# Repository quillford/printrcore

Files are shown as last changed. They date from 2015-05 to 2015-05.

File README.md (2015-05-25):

# smartcore
the simple and cheap corexy from smartfriendz

Note: this is still a work in progress

# Printrbot Simple
this branch concerns converting your Printrbot Simple into a smartcore

Most of the vitamins (non printable parts) can be reused from the printrbot (e.g. printrboard, rods).

# OpenJSCAD Parameters
These are the parameters you should enter in OpenJSCAD

For the stock printrbot simple 1405:

* Output Resolution: 32
* Print width: 110
* Print height: 100
* Print depth: 100
* Box Wood thickness: whatever you are using
* X Y Rods diameter: ~8.1 (can be increased if needed)
* Z Rods diameter: ~8.1 (can be increased if needed)
* Z threaded rods: true
* Stepper motors type: nema17

# Reused Vitamins
* Smooth Rods
* Power supply
* Printrboard
* endstops
* Z probe
* bed
* Hotend
* Extruder (Possibly)
* Motors
* LM8UU Bearings
* Fan

# New Vitamins
* Bowden push fit connectors
* Bowden tube
* GT2 Belt (longer than stock printrbot)
* 608zz bearings
* Wood (for frame)
* Heated bed (optional but recommended)

# Extra Printed Parts
Needed:

* [JHead to Ubis adapter](https://github.com/lordofhyphens/jheadtoubis/blob/master/ubis_jhead_adapter_bracket.stl)

Optional:

* [Printrboard cover](http://www.thingiverse.com/thing:278789/#files)

# Build Notes
* The X axis endstop wires will need to be extended.

# Heated Bed
This is an optional but recommended upgrade for the Printrbot/Smartcore.

Sources:
* [Amazon - Silicon Heater](http://www.amazon.com/100x100mm-Silicone-Rubber-Heater-Printer/dp/B00I50G4O8)
* [Official Printrbot heated bed](http://printrbot.com/shop/heated-bed-upgrade-for-makers-kit-1405/)
* [Ebay - PCB Heater](http://www.ebay.com/itm/Prewired-Heatbed-For-Printrbot-Simple-4-65-X-7-25-Heated-Bed-for-3D-Printing-/251620873437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)

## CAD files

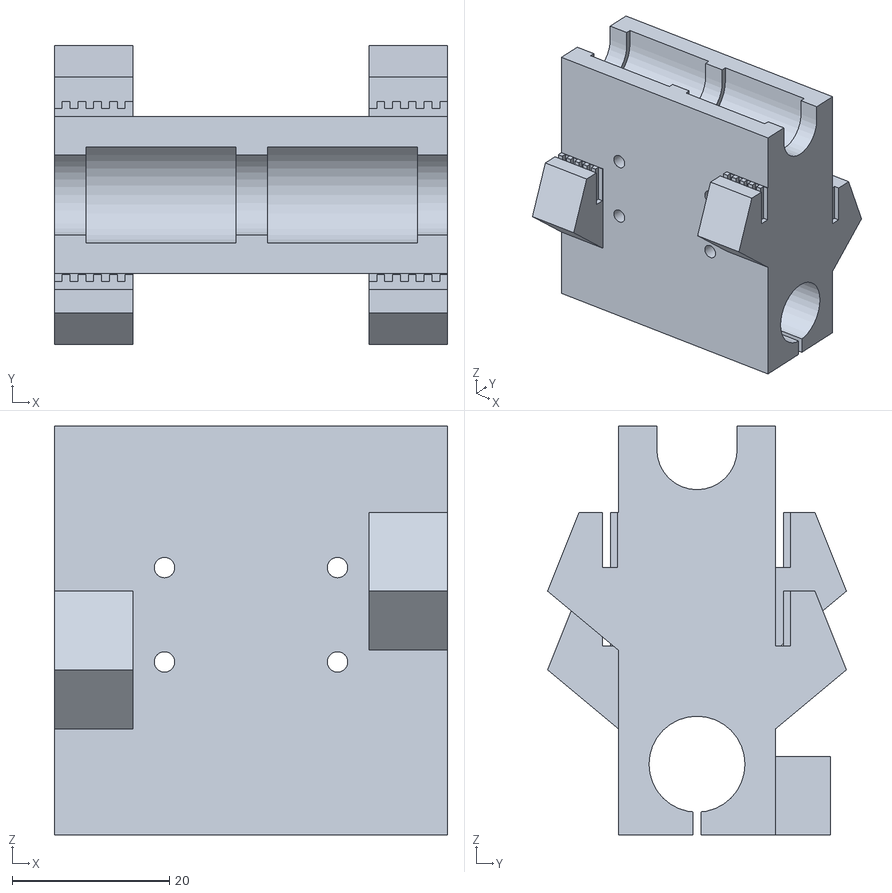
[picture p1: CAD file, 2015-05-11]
stl/separate parts/basic version/head.stl
50.0 x 38.0 x 52.0

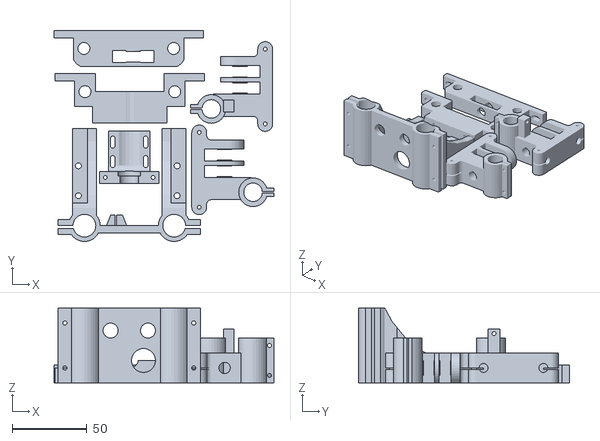
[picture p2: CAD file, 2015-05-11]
stl/smartrapcore_plate1.stl
147.1 x 141.1 x 50.0

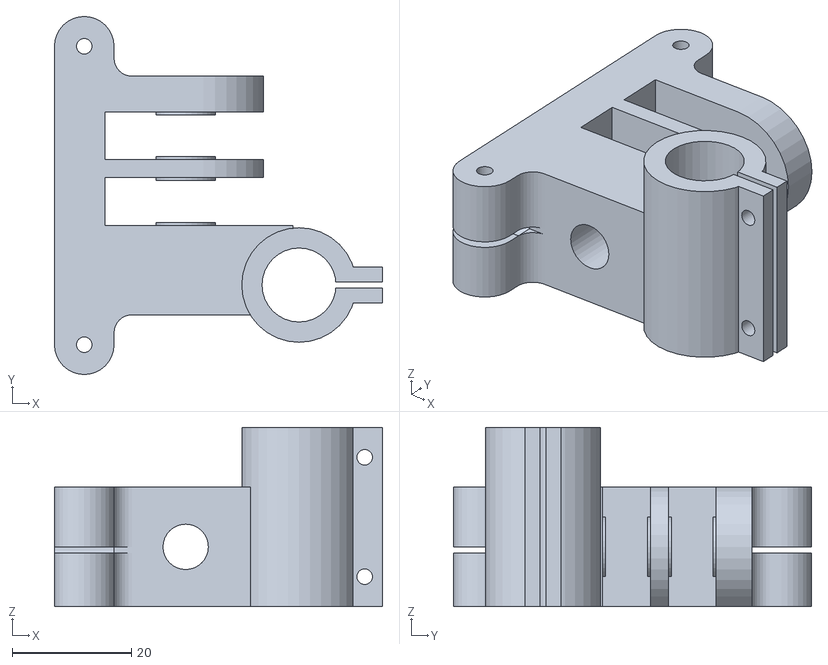
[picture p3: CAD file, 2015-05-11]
stl/separate parts/basic version/Yslide_right.stl
55.0 x 60.0 x 30.0

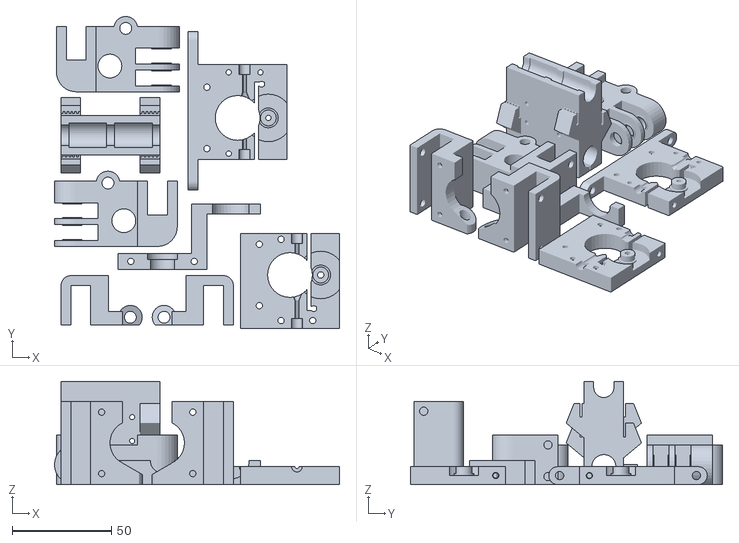
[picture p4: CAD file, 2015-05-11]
stl/smartrapcore_plate2.stl
143.9 x 157.4 x 52.0

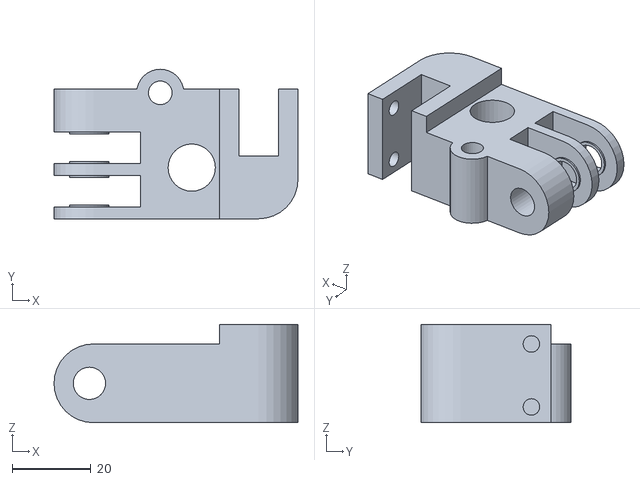
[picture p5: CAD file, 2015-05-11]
stl/separate parts/basic version/XYbearings_left.stl
62.0 x 38.0 x 25.0

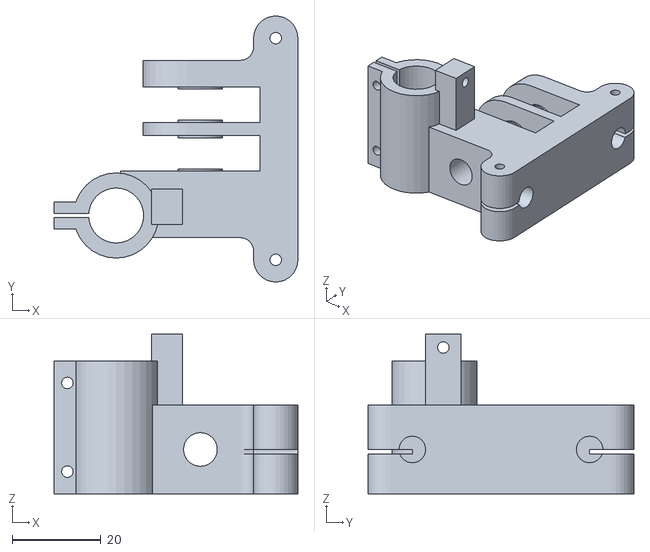
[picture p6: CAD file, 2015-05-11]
stl/separate parts/basic version/Yslide_left.stl
55.0 x 60.0 x 36.0

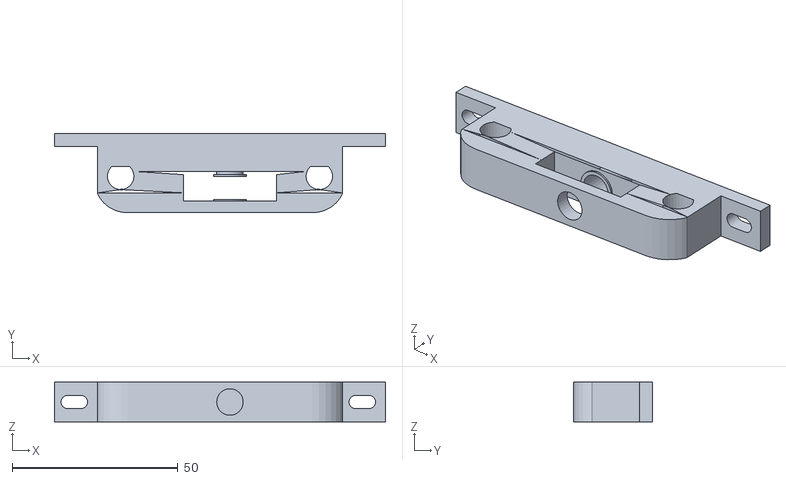
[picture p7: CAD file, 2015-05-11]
stl/separate parts/basic version/Ztop.stl
100.0 x 24.0 x 12.0

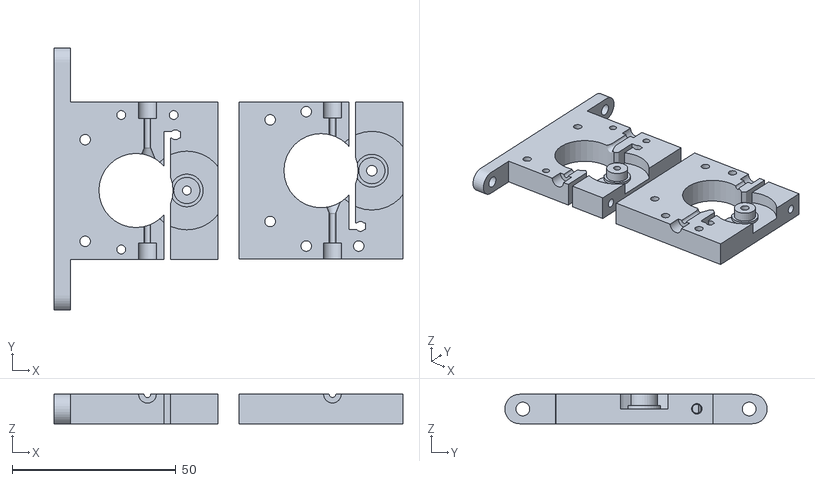
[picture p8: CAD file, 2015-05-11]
stl/separate parts/basic version/extruder_mk8_doublepressfit.stl
106.4 x 80.0 x 9.00

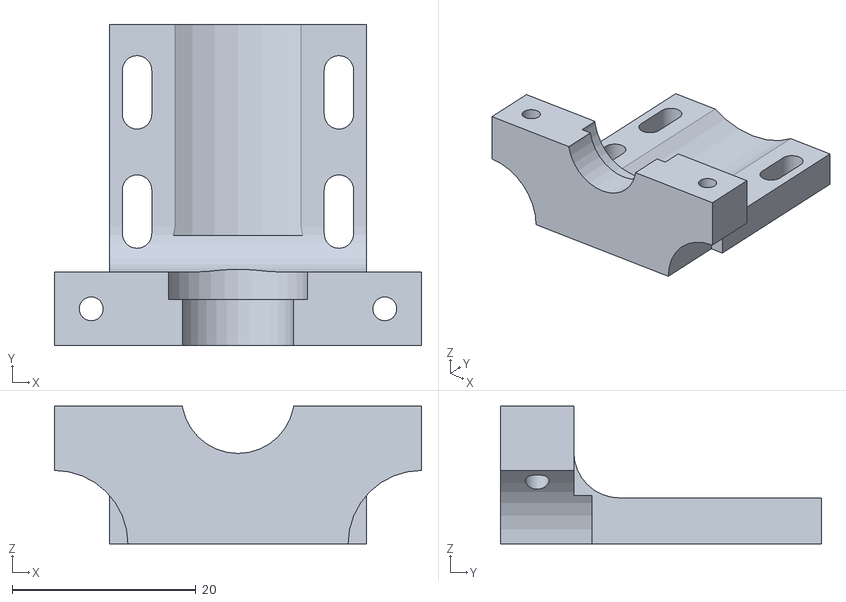
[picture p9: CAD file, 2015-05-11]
stl/separate parts/basic version/jhead_attach.stl
40.0 x 35.0 x 15.0

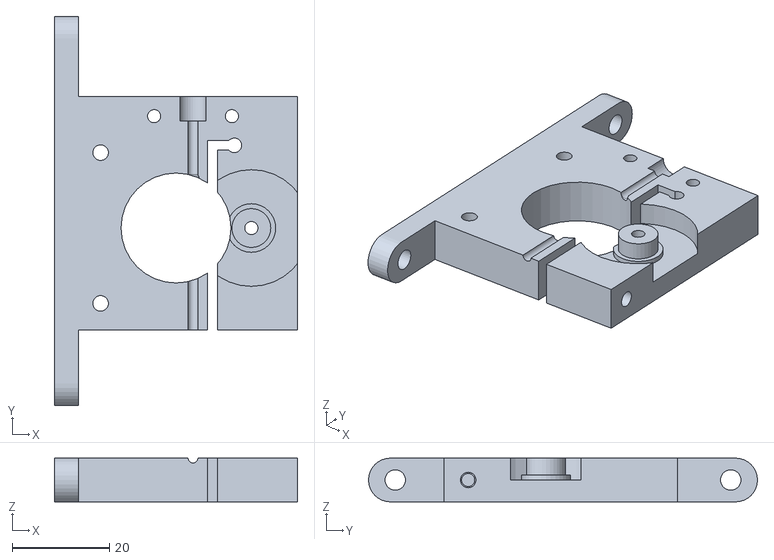
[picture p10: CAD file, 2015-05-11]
stl/separate parts/basic version/extruder_bowden_bottom_mk8.stl
50.0 x 80.0 x 9.00

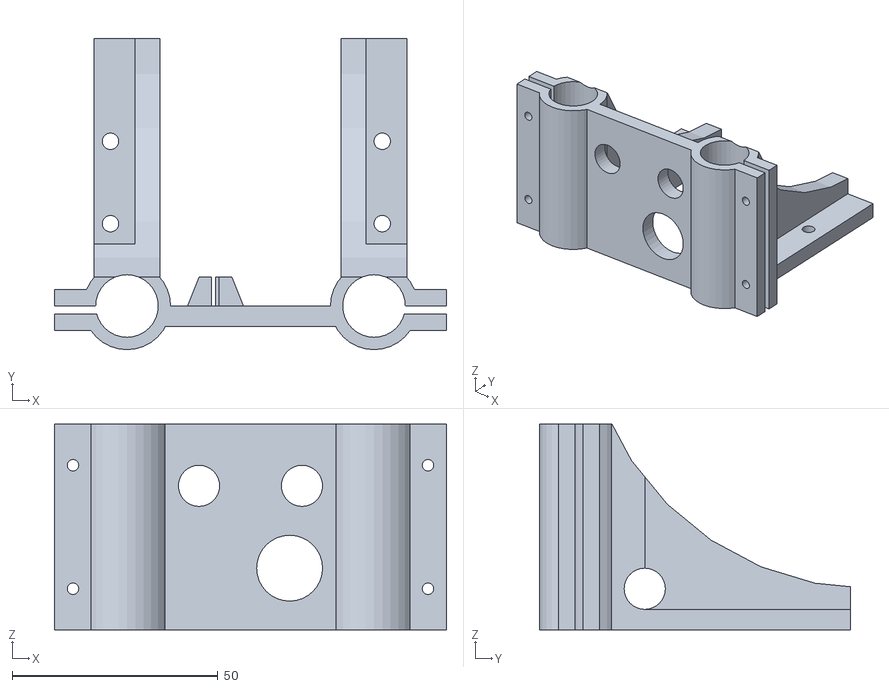
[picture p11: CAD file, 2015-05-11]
stl/separate parts/basic version/Zslide.stl
95.2 x 75.6 x 50.0

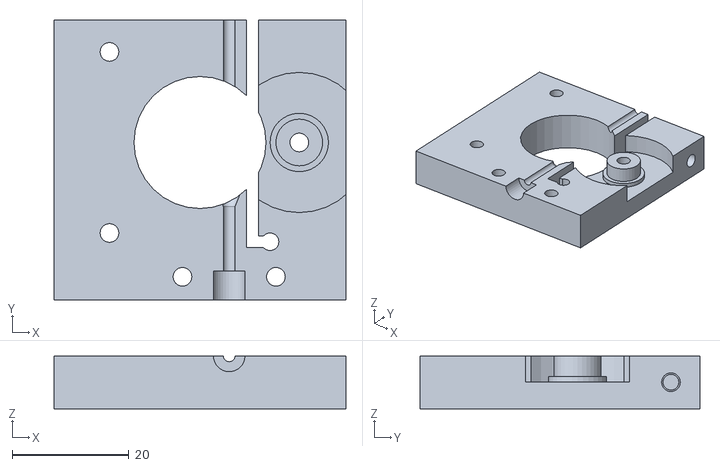
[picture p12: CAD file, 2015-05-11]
stl/separate parts/basic version/extruder_bowden_top_mk7.stl
50.0 x 48.0 x 9.00

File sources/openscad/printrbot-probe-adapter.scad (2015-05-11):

outer_dim=18.2;
probe_dim=12;
rim_dim=outer_dim+3;

length=8.31 + 56.28;

difference() {
  union() {
    cylinder(r=rim_dim/2, h=2);
    cylinder(r=outer_dim/2, h=length);
  }
  cylinder(r=probe_dim/2, h=length, $fs=0.1);
}

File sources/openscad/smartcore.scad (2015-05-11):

/**********

Smartcore : L'empileuse

author= serge.vi / smartfriendz
licence : GPL
version: 0.1
date: 11 / 2014



TODO:





***********/

// global s - updated from interface but need to be avalaible in all modules
_globalResolution=8;
_woodsupport=false;
_globalWidth=300; // exernal dimension of the all printer
_globalHeight=300; // exernal dimension of the all printer
_globalDepth=300; // exernal dimension of the all printer
_printableWidth=200;
_printableDepth=200;
_printableHeight=150;
_wallThickness=10; // box wood thickness
_XYrodsDiam=6; // usually 6 or 8 .. or 10? 
_XYlmDiam=12; // lm6uu, lm8uu ... will be calculated from rods diam
_ZrodsDiam=8; // usually 6 or 8 .. or 10? 
_ZlmDiam=15; // lm6uu, lm8uu ... will be calculated from rods diam
_nemaXYZ=42;  // nema 14 , nema 17 
_XrodsWidth=40; //space between rods on X axis
_ZrodsWidth=80; //space between rods on Z axis
_extrusionType = 0; // 0 bowden 1 direct
 XrodLength = 300; // will be calculated in main from parameters.
 YrodLength = 300; // will be calculated in main from parameters.
 ZrodLength = 300; // will be calculated in main from parameters.
 _rodsSupportThickness = 3; // thickness around rods for all supports
 outputPlateWidth = 180; //used when output to printable plates for elements
 outputPlateDepth = 180;
 mk7Diam = 10;

// global for work
 _bearingsDepth = 35; 
 XaxisOffset = -80;
 _ZaxisOffset = -30;
 endxJheadAttachHolesWidth = 32;




/*
    _globalDepth = _printableDepth + 120; // = motor support depth + bearings depth + head depth /2
    _globalWidth = _printableWidth + 120; // = motor uspport width + bearings width + head width /2
    _globalHeight = _printableHeight + 100; // bottom = 40mm head = 40 mm + extra loose.

    XrodLength = _globalWidth - 2*(40 + 3); // 40: slideY width , 3: offset slideY from wall.
    YrodLength = _globalDepth - (_nemaXYZ -5) - (_bearingsDepth -5); // 5: rod support inside parts.
    ZrodLength = _globalHeight -40;


    echo("wood depth="+_globalDepth + " width="+_globalWidth+" height:"+_globalHeight);
    echo("X rod length="+XrodLength + " Y rod length="+YrodLength+" Zrodlength="+ZrodLength);
    // calculate some usefull s
     ztopbottomX = (_ZrodsWidth+_ZrodsDiam+(_rodsSupportThickness*2))/2;
     zslideX = (_ZrodsWidth+_ZlmDiam+(_rodsSupportThickness*2))/2;
*/
// -----------------  printed elements 

assembly();
zBottom();

module zTop(){
     width = _ZrodsWidth+_ZrodsDiam+(_rodsSupportThickness*2);
     height = 12;
     depth = 22;
     insideWidth = 60;

    if(output==1){
        union(){
            rotate([90,0,0])
            translate([3,0,0])
            bearing608z();
        };
    }
    union(){
        difference(){
            //main
            cube([width,depth,height],center=true);
            // inside form
            translate([0,-5,0])
            cube([insideWidth,depth,height],center=true);
            //screw left
            rotate([90,90,0])
            translate([-(insideWidth)/2+4,20,0])
            slottedHole(4,8,depth);
            //screw right
		rotate([90,90,0])
		translate([(insideWidth)/2-9,20,0])
            slottedHole(4,8,depth);
            // z rod left
		translate([-_ZrodsWidth/2,-2,-height/2])
            cylinder(r= _ZrodsDiam/2,h=height,fn=_globalResolution);
            //z rod right
		translate([_ZrodsWidth/2,-2,-height/2])
            cylinder(r=_ZrodsDiam/2,h=height,fn=_globalResolution);
            // chamfer
		rotate([90,0,0])
		translate([-(insideWidth)/2-5,-7,-height/2])
            roundBoolean(10,10,20,height,"bl");
		rotate([90,0,-90])
		translate([(insideWidth)/2+5,-7,-height/2])
            roundBoolean(10,10,20,height,"bl");

        };
		rotate([90,0,0])
		translate([3,6,0])
        bearingSupport(7);
    };
}

module zBottom(){
     width = _ZrodsWidth+_ZrodsDiam+(_rodsSupportThickness*2);
     height = 10;
     depth = 22;
     attachdiam = 12;
    difference(){
        //main
        union(){
            cube([width,depth,height],center=true);
            translate([0,-10,0])
            cube([width/2,depth,10],center=true);
            // screws attach form right
		rotate([-90,0,0])
		translate([width/4+attachdiam/2,depth/2-5,height])
            cylinder(r=attachdiam/2,h=5,fn=_globalResolution);
		translate([width/4+attachdiam/2,depth/2-2.5,height-attachdiam/2])
            cube([attachdiam,5,attachdiam],center=true);
            // screws attach form left
		rotate([-90,0,0])
		translate([-width/4-attachdiam/2,depth/2-5,height])
            cylinder(r=attachdiam/2,h=5,fn=_globalResolution);
		translate([-width/4-attachdiam/2,depth/2-2.5,height-attachdiam/2])
            cube([attachdiam,5,attachdiam],center=true);
            
	};
        // inside form
	rotate([90,0,0])
	translate([0,0,_nemaXYZ/2-height/2])
        nemaHole(_nemaXYZ);
	translate([0,10,0])
        cube([width/2,depth,height],center=true);
        // z rod left
	translate([-_ZrodsWidth/2,-2,-height/2])
        cylinder(r=_ZrodsDiam/2,h=height,fn=_globalResolution);
        //z rod right
	translate([_ZrodsWidth/2,-2,-height/2])
        cylinder(r=_ZrodsDiam/2,h=height,fn=_globalResolution);
        //screw holes
        // screws attach form
	rotate([-90,0,0])
	translate([width/4+attachdiam/2,depth/2-5,height])
        cylinder(r=2,h=5,fn=_globalResolution);
	rotate([-90,0,0])
	translate([-width/4-attachdiam/2,depth/2-5,height])
        cylinder(r=2,h=5,fn=_globalResolution);
        
};
}

module slideZ(){
     width = _ZrodsWidth-5;
     height = 50;
     depth = 5;
     insideWidth = 35;
    difference(){
        //main form
        union(){
            cube([width,depth,height]);
		rotate([90,0,0])
        translate([width/2-10,1,height-13])
            Gt2Holder2();
        
            // lm8uu holes
            translate([0,0,0])
            cylinder(r=_ZlmDiam/2+3,h=height,fn=_globalResolution);
            translate([_ZrodsWidth,0,0])
            cylinder(r=_ZlmDiam/2+3,h=height,fn=_globalResolution);

            // side forms for lm8 attach
            translate([_ZrodsWidth+7,-4,0])
            cube([10,10,height]);
            translate([-17,-4,0])
            cube([10,10,height]);

            // extra forms front bearings holes
            translate([-5,-75,0])
            cube([10,80,height]);
            translate([_ZrodsWidth-5,-75,0])
            cube([10,80,height]);
            
        };
        // big hole middle
        rotate([90,0,0])
        translate([width/2+15,40,height/2+10])
        cylinder(r=10,h=50,fn=_globalResolution);
        rotate([90,0,0])
        translate([width/2-10,40,height/2-10])
        cylinder(r=10,h=50,fn=_globalResolution);
        //  boolean front horizontal
        rotate([0,90,0])
        translate([-20,-80,-35])
        cylinder(r=80,h=width+40,fn=_globalResolution);
        rotate([0,90,0])
        translate([-20,-15,height-10])
        cylinder(r=5,h=width+40,fn=_globalResolution);
        rotate([0,90,0])
        translate([-20,-35,height-13])
        cylinder(r=3,h=width+40,fn=_globalResolution);
        // z rod left linear bearing lm
        cylinder(r=_ZlmDiam/2,h=height,fn=_globalResolution);
        //z rod right linear bearing lm
        translate([_ZrodsWidth,0,0])
        cylinder(r=_ZlmDiam/2,h=height,fn=_globalResolution);
        // side holes for lm8 attach
        translate([_ZrodsWidth+5,0,0])
        cube([12,2,height]);
        translate([-18,0,0])
        cube([12,2,height]);
        // side holes for lm8 screws
        rotate([90,0,0])
        translate([_ZrodsWidth+12,20,height-10])
        cylinder(r=1.4,h=30,fn=_globalResolution);
        rotate([90,0,0])
        translate([_ZrodsWidth+12,20,10])
        cylinder(r=1.4,h=30,fn=_globalResolution);
        rotate([90,0,0])
        translate([-12,20,height-10])
        cylinder(r=1.4,h=30,fn=_globalResolution);
        rotate([90,0,0])
        translate([-12,20,10])
        cylinder(r=1.4,h=30,fn=_globalResolution);
        //bottom holes

        //cylinder(r=2.4,h=10,fn=_globalResolution).rotateX(83).rotateZ(5).translate([0,-7,10]);
        //cylinder(r=2.4,h=10,fn=_globalResolution).rotateX(83).rotateZ(-5).translate([_ZrodsWidth,-7,10]);
        // top holes
        translate([0,-20,height-30])
        cylinder(r=1.4,h=30,fn=_globalResolution);
        translate([_ZrodsWidth,-20,height-30])
        cylinder(r=1.4,h=30,fn=_globalResolution);
        translate([0,-65,height-30])
        cylinder(r=1.4,h=30,fn=_globalResolution);
        translate([_ZrodsWidth,-65,height-30])
        cylinder(r=1.4,h=30,fn=_globalResolution);
        // special hole in gt2 holder to be able to get the belt out .. but still printable vertically.
        rotate([0,-90,0])
        translate([width/2+5,-10,height-15])
        linear_extrude(height=20,polygon([[0,0],[6,0],[4,10],[2,10]]));

        
    };
}
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

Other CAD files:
stl/separate parts/basic version/jhead_adaptor.stl
stl/separate parts/basic version/XYbearings_right.stl
stl/separate parts/basic version/extruder_bowden_top_mk8.stl
stl/separate parts/basic version/extruder_bowden_bottom_mk7.stl
sources/blender/sc_12_plates.blend

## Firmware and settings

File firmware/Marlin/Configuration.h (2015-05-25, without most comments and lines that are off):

#define CONFIGURATION_H
#include "boards.h"
#define STRING_VERSION_CONFIG_H __DATE__ " " __TIME__ // build date and time
#define STRING_CONFIG_H_AUTHOR "(none, default config)" // Who made the changes.
#define SERIAL_PORT 0
#define BAUDRATE 250000
  #define MOTHERBOARD BOARD_PRINTRBOARD
#define SDSUPPORT
#define EXTRUDERS 1
#define POWER_SUPPLY 1
#define TEMP_SENSOR_0 1
#define TEMP_SENSOR_1 0
#define TEMP_SENSOR_2 0
#define TEMP_SENSOR_BED 1
#define MAX_REDUNDANT_TEMP_SENSOR_DIFF 10
#define TEMP_RESIDENCY_TIME 10  // (seconds)
#define TEMP_HYSTERESIS 3       // (degC) range of +/- temperatures considered "close" to the target one
#define TEMP_WINDOW     1       // (degC) Window around target to start the residency timer x degC early.
#define HEATER_0_MINTEMP 5
#define HEATER_1_MINTEMP 5
#define HEATER_2_MINTEMP 5
#define BED_MINTEMP 5
#define HEATER_0_MAXTEMP 275
#define HEATER_1_MAXTEMP 275
#define HEATER_2_MAXTEMP 275
#define BED_MAXTEMP 150
#define PIDTEMP
#define BANG_MAX 255 // limits current to nozzle while in bang-bang mode; 255=full current
#define PID_MAX BANG_MAX // limits current to nozzle while PID is active (see PID_FUNCTIONAL_RANGE below); 255=full current
  #define PID_FUNCTIONAL_RANGE 10 // If the temperature difference between the target temperature and the actual temperature
  #define PID_INTEGRAL_DRIVE_MAX PID_MAX  //limit for the integral term
  #define K1 0.95 //smoothing factor within the PID
  #define PID_dT ((OVERSAMPLENR * 10.0)/(F_CPU / 64.0 / 256.0)) //sampling period of the temperature routine
 #define DEFAULT_Kp  52.65
 #define DEFAULT_Ki 6.43
 #define DEFAULT_Kd 107.83
#define PIDTEMPBED
#define MAX_BED_POWER 255 // limits duty cycle to bed; 255=full current
     #define  DEFAULT_bedKp 219.58
 #define  DEFAULT_bedKi 32.29
 #define  DEFAULT_bedKd 373.26
#define PREVENT_DANGEROUS_EXTRUDE
#define PREVENT_LENGTHY_EXTRUDE
#define EXTRUDE_MINTEMP 170
#define EXTRUDE_MAXLENGTH (X_MAX_LENGTH+Y_MAX_LENGTH) //prevent extrusion of very large distances.
#define COREXY
#define ENDSTOPPULLUPS // Comment this out (using // at the start of the line) to disable the endstop pullup resistors
  #define ENDSTOPPULLUP_XMAX
  #define ENDSTOPPULLUP_YMAX
  #define ENDSTOPPULLUP_ZMAX
  #define ENDSTOPPULLUP_XMIN
  #define ENDSTOPPULLUP_YMIN
  #define ENDSTOPPULLUP_ZMIN
const bool X_MIN_ENDSTOP_INVERTING = false; // set to true to invert the logic of the endstop.
const bool Y_MIN_ENDSTOP_INVERTING = false; // set to true to invert the logic of the endstop.
const bool Z_MIN_ENDSTOP_INVERTING = true; // set to true to invert the logic of the endstop.
const bool X_MAX_ENDSTOP_INVERTING = true; // set to true to invert the logic of the endstop.
const bool Y_MAX_ENDSTOP_INVERTING = true; // set to true to invert the logic of the endstop.
const bool Z_MAX_ENDSTOP_INVERTING = true; // set to true to invert the logic of the endstop.
#define DISABLE_MAX_ENDSTOPS
#if defined(COREXY) && !defined(DISABLE_MAX_ENDSTOPS)
  #define DISABLE_MAX_ENDSTOPS
#endif
#define X_ENABLE_ON 0
#define Y_ENABLE_ON 0
#define Z_ENABLE_ON 0
#define E_ENABLE_ON 0 // For all extruders
#define DISABLE_X false
#define DISABLE_Y false
#define DISABLE_Z false
#define DISABLE_E false // For all extruders
#define DISABLE_INACTIVE_EXTRUDER true //disable only inactive extruders and keep active extruder enabled
#define INVERT_X_DIR true    // for Mendel set to false, for Orca set to true
#define INVERT_Y_DIR false    // for Mendel set to true, for Orca set to false
#define INVERT_Z_DIR true     // for Mendel set to false, for Orca set to true
#define INVERT_E0_DIR false   // for direct drive extruder v9 set to true, for geared extruder set to false
#define INVERT_E1_DIR false    // for direct drive extruder v9 set to true, for geared extruder set to false
#define INVERT_E2_DIR false   // for direct drive extruder v9 set to true, for geared extruder set to false
#define X_HOME_DIR -1
#define Y_HOME_DIR -1
#define Z_HOME_DIR -1
#define min_software_endstops true // If true, axis won't move to coordinates less than HOME_POS.
#define max_software_endstops true  // If true, axis won't move to coordinates greater than the defined lengths below.
#define X_MAX_POS 100
#define X_MIN_POS 0
#define Y_MAX_POS 100
#define Y_MIN_POS 0
#define Z_MAX_POS 140
#define Z_MIN_POS 0
#define X_MAX_LENGTH (X_MAX_POS - X_MIN_POS)
#define Y_MAX_LENGTH (Y_MAX_POS - Y_MIN_POS)
#define Z_MAX_LENGTH (Z_MAX_POS - Z_MIN_POS)
#define ENABLE_AUTO_BED_LEVELING // Delete the comment to enable (remove // at the start of the line)
#define Z_PROBE_REPEATABILITY_TEST  // If not commented out, Z-Probe Repeatability test will be included if Auto Bed Leveling is Enabled.
  #define AUTO_BED_LEVELING_GRID
    #define LEFT_PROBE_BED_POSITION 0
    #define RIGHT_PROBE_BED_POSITION 70
    #define BACK_PROBE_BED_POSITION 90
    #define FRONT_PROBE_BED_POSITION 0
    #define AUTO_BED_LEVELING_GRID_POINTS 3
  #define X_PROBE_OFFSET_FROM_EXTRUDER -16
  #define Y_PROBE_OFFSET_FROM_EXTRUDER 0
  #define Z_PROBE_OFFSET_FROM_EXTRUDER -1
  #define Z_RAISE_BEFORE_HOMING 4       // (in mm) Raise Z before homing (G28) for Probe Clearance.
  #define XY_TRAVEL_SPEED 8000         // X and Y axis travel speed between probes, in mm/min
  #define Z_RAISE_BEFORE_PROBING 15    //How much the extruder will be raised before traveling to the first probing point.
  #define Z_RAISE_BETWEEN_PROBINGS 5  //How much the extruder will be raised when traveling from between next probing points
  #define Z_SAFE_HOMING   // This feature is meant to avoid Z homing with probe outside the bed area.
    #define Z_SAFE_HOMING_X_POINT 0    // X point for Z homing when homing all axis (G28)
    #define Z_SAFE_HOMING_Y_POINT 0    // Y point for Z homing when homing all axis (G28)
    #if X_PROBE_OFFSET_FROM_EXTRUDER < 0
      #if (-(X_PROBE_OFFSET_FROM_EXTRUDER * AUTO_BED_LEVELING_GRID_POINTS) >= (RIGHT_PROBE_BED_POSITION - LEFT_PROBE_BED_POSITION))
	     #error "The X axis probing range is not enough to fit all the points defined in AUTO_BED_LEVELING_GRID_POINTS"
	  #endif
	#else
      #if ((X_PROBE_OFFSET_FROM_EXTRUDER * AUTO_BED_LEVELING_GRID_POINTS) >= (RIGHT_PROBE_BED_POSITION - LEFT_PROBE_BED_POSITION))
	     #error "The X axis probing range is not enough to fit all the points defined in AUTO_BED_LEVELING_GRID_POINTS"
	  #endif
	#endif
    #if Y_PROBE_OFFSET_FROM_EXTRUDER < 0
      #if (-(Y_PROBE_OFFSET_FROM_EXTRUDER * AUTO_BED_LEVELING_GRID_POINTS) >= (BACK_PROBE_BED_POSITION - FRONT_PROBE_BED_POSITION))
	     #error "The Y axis probing range is not enough to fit all the points defined in AUTO_BED_LEVELING_GRID_POINTS"
	  #endif
	#else
      #if ((Y_PROBE_OFFSET_FROM_EXTRUDER * AUTO_BED_LEVELING_GRID_POINTS) >= (BACK_PROBE_BED_POSITION - FRONT_PROBE_BED_POSITION))
	     #error "The Y axis probing range is not enough to fit all the points defined in AUTO_BED_LEVELING_GRID_POINTS"
	  #endif
	#endif
#define MANUAL_X_HOME_POS 0
#define MANUAL_Y_HOME_POS 0
#define MANUAL_Z_HOME_POS 0
#define NUM_AXIS 4 // The axis order in all axis related arrays is X, Y, Z, E
#define HOMING_FEEDRATE {50*60, 50*60, 50*60, 0}  // set the homing speeds (mm/min)
#define DEFAULT_AXIS_STEPS_PER_UNIT   {80,80,80,119.768}  // default steps per unit for Ultimaker
#define DEFAULT_MAX_FEEDRATE          {500, 500, 5, 25}    // (mm/sec)
#define DEFAULT_MAX_ACCELERATION      {6000,6000,2000,10000}    // X, Y, Z, E maximum start speed for accelerated moves. E default values are good for Skeinforge 40+, for older versions raise them a lot.
#define DEFAULT_ACCELERATION          3000    // X, Y, Z and E max acceleration in mm/s^2 for printing moves
#define DEFAULT_RETRACT_ACCELERATION  3000   // X, Y, Z and E max acceleration in mm/s^2 for retracts
#define DEFAULT_XYJERK                20.0    // (mm/sec)
#define DEFAULT_ZJERK                 10.0     // (mm/sec)
#define DEFAULT_EJERK                 5.0    // (mm/sec)
#define CUSTOM_M_CODES
  #define CUSTOM_M_CODE_SET_Z_PROBE_OFFSET 851
  #define Z_PROBE_OFFSET_RANGE_MIN -15
  #define Z_PROBE_OFFSET_RANGE_MAX 10
#define EEPROM_SETTINGS
#define PLA_PREHEAT_HOTEND_TEMP 180
#define PLA_PREHEAT_HPB_TEMP 70
#define PLA_PREHEAT_FAN_SPEED 255   // Insert Value between 0 and 255
#define ABS_PREHEAT_HOTEND_TEMP 240
#define ABS_PREHEAT_HPB_TEMP 100
#define ABS_PREHEAT_FAN_SPEED 255   // Insert Value between 0 and 255
#define SDSUPPORT // Enable SD Card Support in Hardware Console
#define SDSLOW // Use slower SD transfer mode (not normally needed - uncomment if you're getting volume init error)
#define SD_CHECK_AND_RETRY // Use CRC checks and retries on the SD communication
#define SOFT_PWM_SCALE 0
#define FILAMENT_SENSOR_EXTRUDER_NUM	0  //The number of the extruder that has the filament sensor (0,1,2)
#define MEASUREMENT_DELAY_CM			14  //measurement delay in cm.  This is the distance from filament sensor to middle of barrel
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

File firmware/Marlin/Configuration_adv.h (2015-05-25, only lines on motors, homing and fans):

#define CONTROLLERFAN_PIN -1 //Pin used for the fan to cool controller (-1 to disable)
#define EXTRUDER_0_AUTO_FAN_PIN   -1
#define EXTRUDER_1_AUTO_FAN_PIN   -1
#define EXTRUDER_2_AUTO_FAN_PIN   -1
#define ENDSTOPS_ONLY_FOR_HOMING // If defined the endstops will only be used for homing
#define X_HOME_RETRACT_MM 5
#define Y_HOME_RETRACT_MM 5
#define Z_HOME_RETRACT_MM 2
#define MICROSTEP1 LOW,LOW
#define MICROSTEP2 HIGH,LOW
#define MICROSTEP4 LOW,HIGH
#define MICROSTEP8 HIGH,HIGH
#define MICROSTEP16 HIGH,HIGH
#define MICROSTEP_MODES {16,16,16,16,16} // [1,2,4,8,16]
#define DIGIPOT_MOTOR_CURRENT {135,135,135,155,135} // Values 0-255 (RAMBO 135 = ~0.75A, 185 = ~1A)
#define DIGIPOT_I2C_MOTOR_CURRENTS {1.0, 1.0, 1.0, 1.0, 1.0, 1.0, 1.0, 1.0}

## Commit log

2015-03-25 Added printrbot simple readme
2015-03-29 Added printrbot jscad
2015-03-30 XYZ Rod diameter 9mm
2015-03-30 Initial settings correct for Printrbot Simple 1405
2015-03-31 Option for bearing outer diameter
2015-03-31 Fixed bearing outer diam parameter
2015-04-01 Added heated beds to README
2015-04-03 Made the Z wide enough for the printrbot standard bed.
2015-04-03 Removed bearing od parameter
    [Configuration.h]
2015-04-03 Rod diameter is now a float
    also, defaults to belt driven Z parameter
2015-04-03 Print height defaults to 100mm
2015-04-04 Added probe diameter parameter
    [Configuration.h]
2015-04-04 Defaults to belt driven Z
2015-04-04 Added Z probe diameter parameter
2015-04-04 1.0.8
    debugging 2 merges about Z. One is Z rods until 12mm an other is Z
    threaded rod.
2015-04-04 10.0.9
    new plate 2 : Ztop bearing hole was too small.
    [Configuration.h, smartcore.scad, smartrapcore_plate2.stl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]
2015-04-05 Added printrboard cober to readme
2015-04-07 Widened arms for Z support for threaded
2015-04-09 Added a (toggleable) fudge factor for the XYZ linear bearings.
2015-04-12 Added munging parameter and moved the z top and zbottom rod spacing a little wider.
2015-04-22 added printrbot adapter for bed probe
    [printrbot-probe-adapter.scad]
2015-04-22 fixed printrbot probe adapter
    [printrbot-probe-adapter.scad, smartcore.scad]
2015-04-29 changed initial print height to 140mm
    140mm Z height fits the stock rods. 150mm didn't
2015-05-15 Partially parameterized the XY bearing length for head
2015-05-17 fixed 1.2 for printrbot initial settings and fixed placement of bottom wall size
2015-05-25 Updated firmware with LoH's marlin config
    [Configuration.h, Configuration_adv.h, Menu Plans.xlsx]
